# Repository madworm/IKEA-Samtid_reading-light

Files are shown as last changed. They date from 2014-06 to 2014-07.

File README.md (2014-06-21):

IKEA-Samtid_reading-light
=========================

LAYOUT FILES: Circuit board to go between the movable beams of the Samtid lamp.

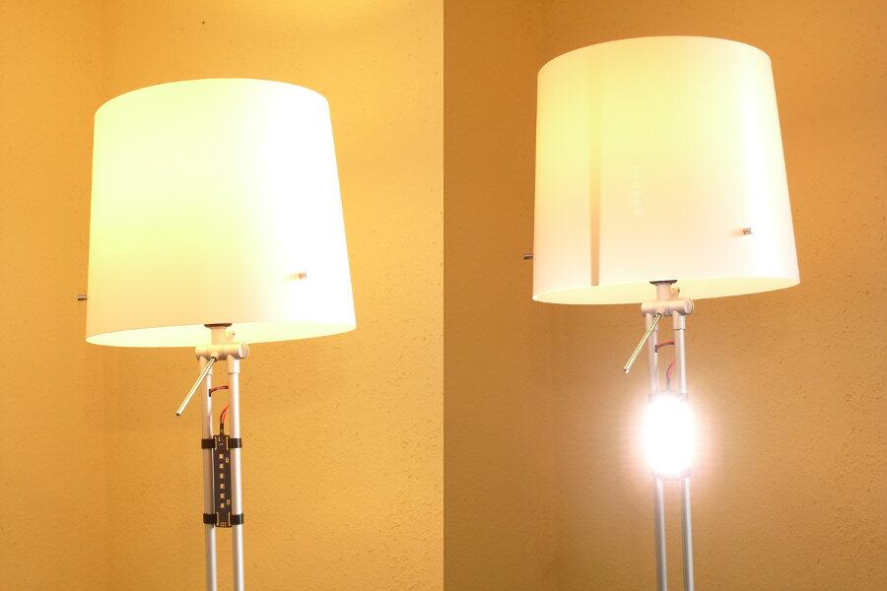
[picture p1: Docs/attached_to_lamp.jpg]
IKEA Samtid


---

Before having PC-boards made, please make sure you know about your manufacturer's peculiarities!
Especially drill-sizes and their tolerances may vary too much and give you trouble.

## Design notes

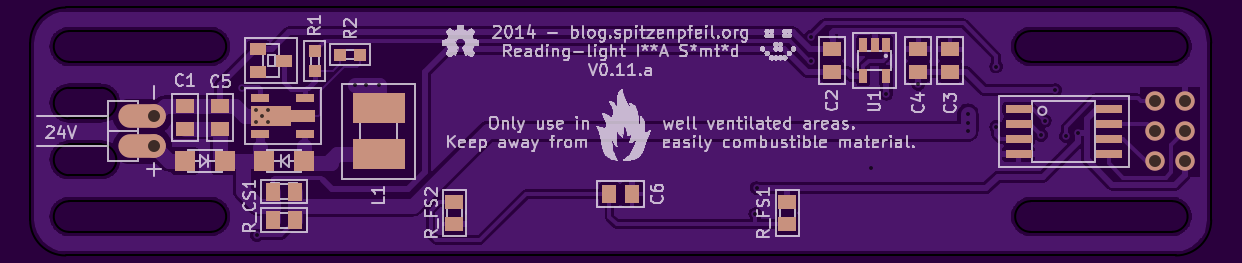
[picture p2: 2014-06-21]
gerber_files/PNGs/IKEA-Samtid_reading-light__back_purple.png

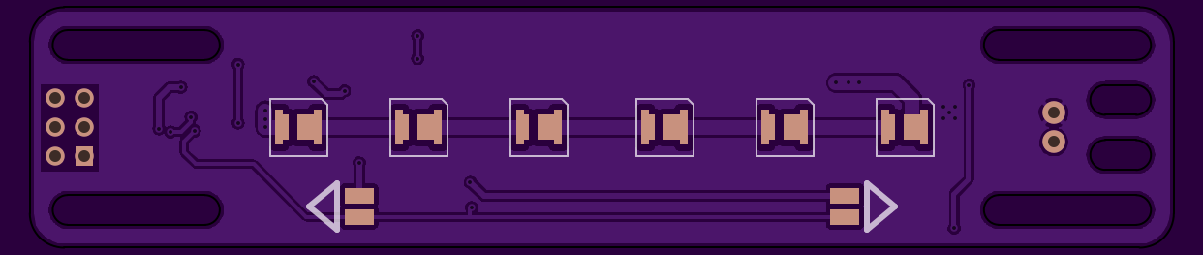
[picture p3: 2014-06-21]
gerber_files/PNGs/IKEA-Samtid_reading-light__front_purple.png

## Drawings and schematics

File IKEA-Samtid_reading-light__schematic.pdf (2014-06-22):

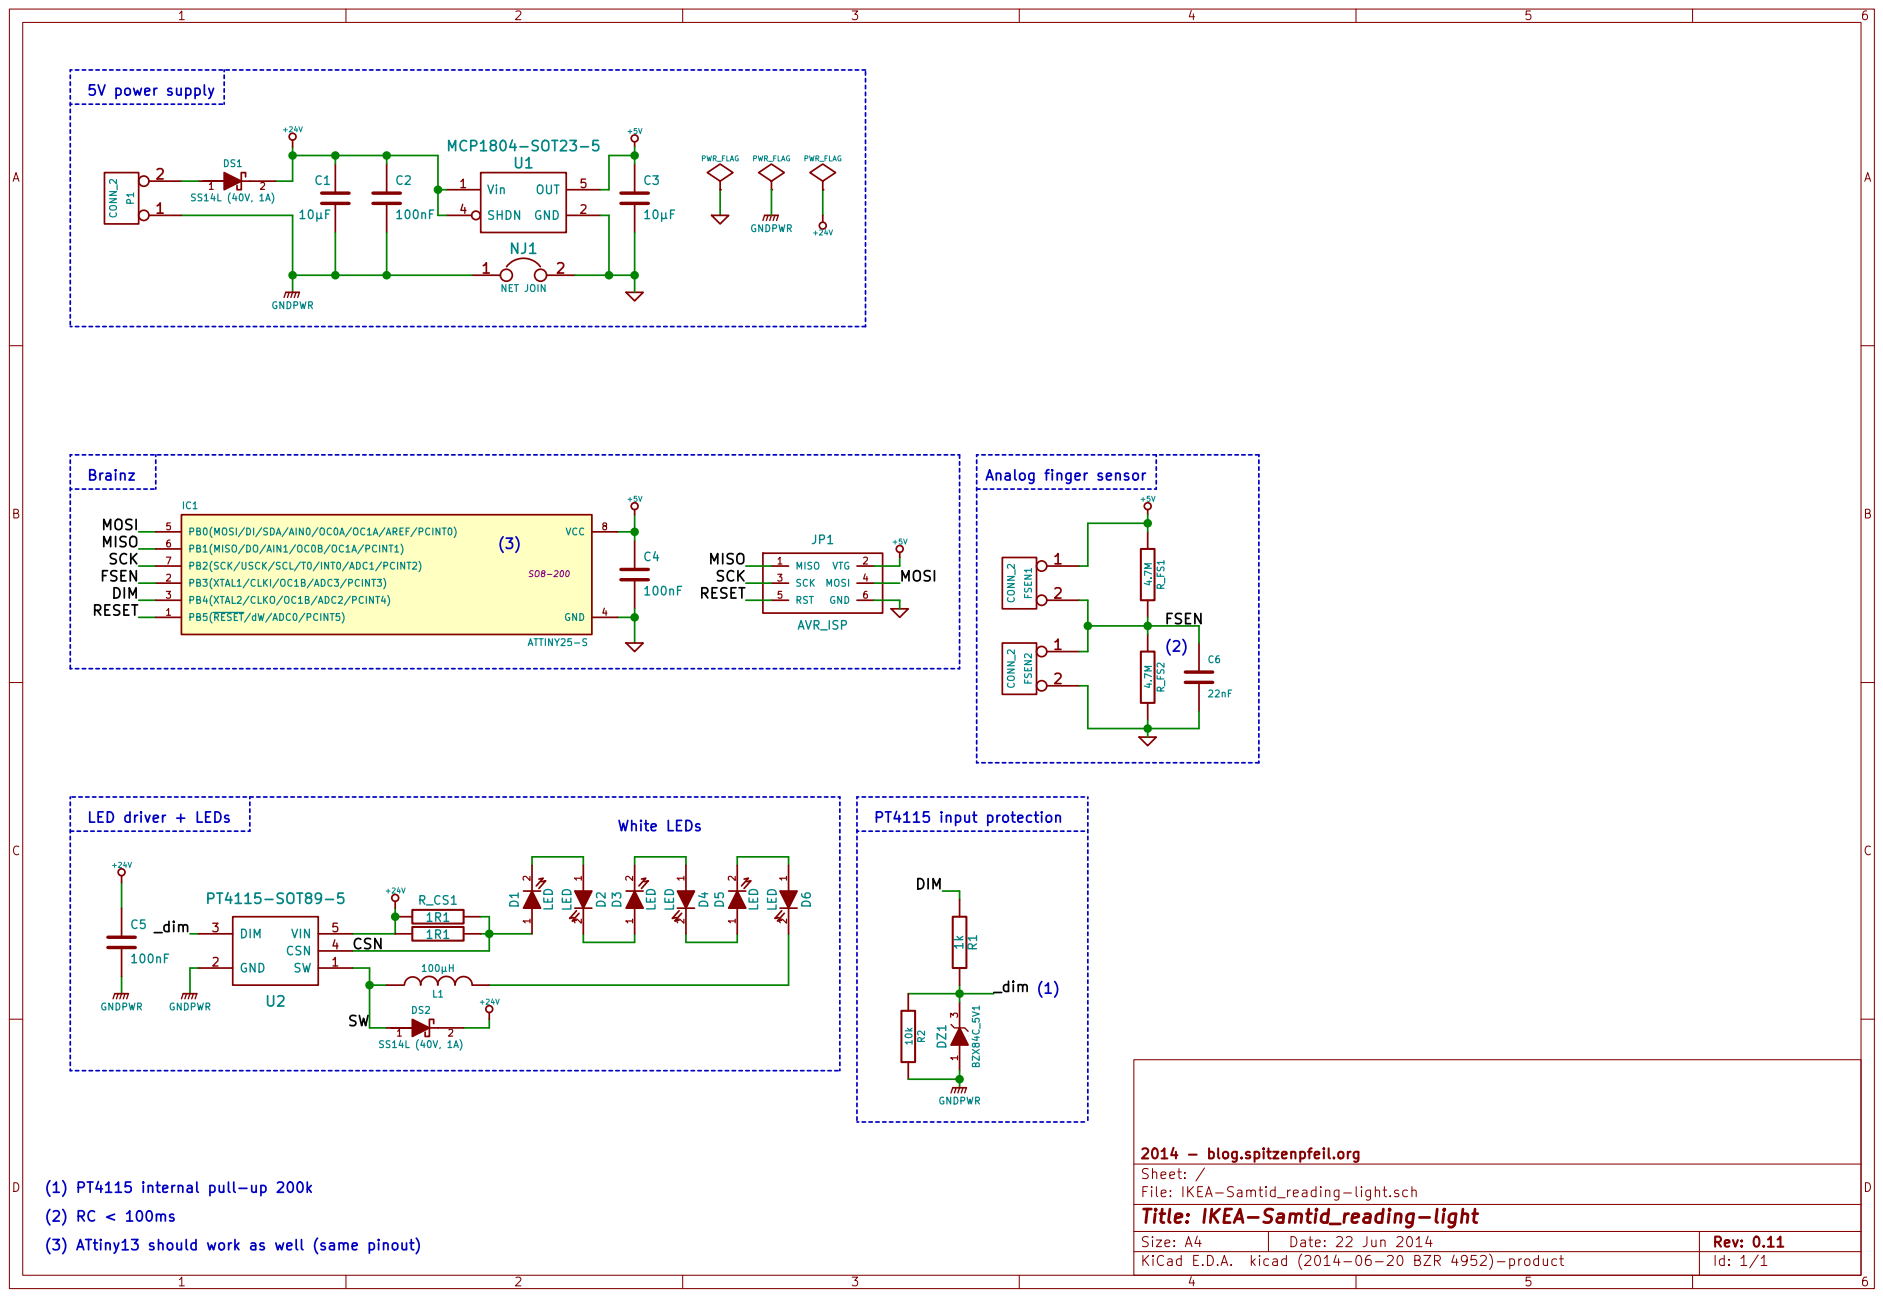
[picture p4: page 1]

PT4115 input protection Brainz LED driver + LEDs

File: IKEA-Samtid_reading-light.sch Sheet: / 2014 - blog.spitzenpfeil.org

(1) PT4115 internal pull-up 200k
(3) ATtiny13 should work as well (same pinout)

Id: 1/1 Title: IKEA-Samtid_reading-light

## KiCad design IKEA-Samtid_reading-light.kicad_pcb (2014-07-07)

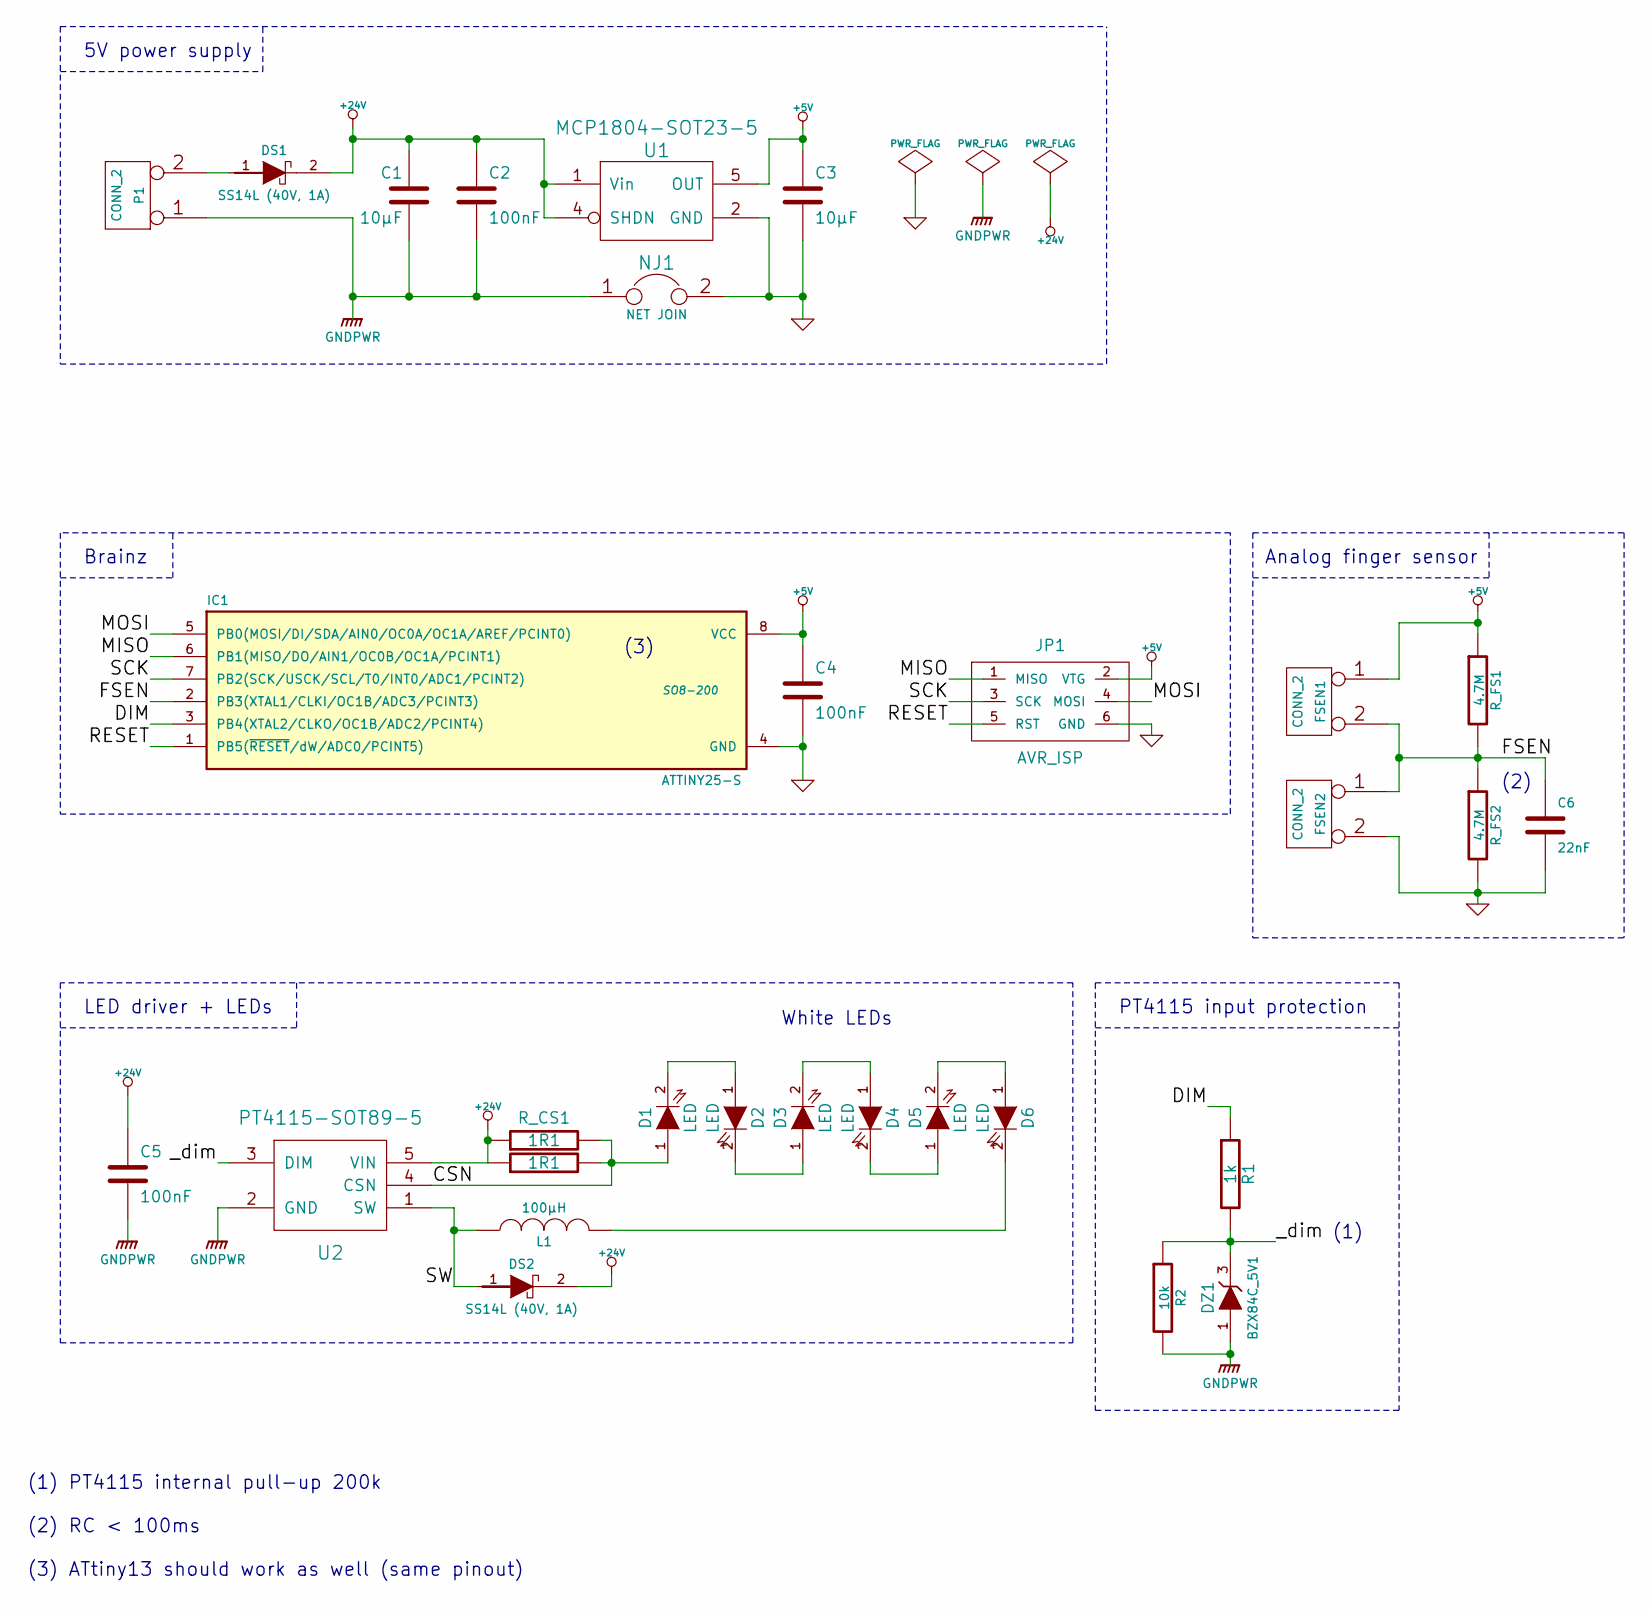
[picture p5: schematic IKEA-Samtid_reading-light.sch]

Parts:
C1, C3: 10µF
C2, C4, C5: 100nF
C6: 22nF
D1, D2, D3, D4, D5, D6: LED
DS1, DS2: SS14L (40V, 1A)
DZ1: BZX84C_5V1
FSEN1, FSEN2: CONN_2
IC1: ATTINY25-S; SO8-200
JP1: AVR_ISP
L1: 100µH
NJ1: NET JOIN
P1: CONN_2
R1: 1k
R2: 10k
R_CS1, R_CS2: 1R1
R_FS1, R_FS2: 4.7M
U1: MCP1804-SOT23-5
U2: PT4115-SOT89-5

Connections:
+5V: C3.1, C4.1, FSEN1.1, IC1.8 (VCC), JP1.2 (VTG), R_FS1.1, U1.5 (OUT)
+24V: C1.1, C2.1, C5.1, DS1.2 (C), DS2.2 (C), R_CS1.1, R_CS2.1, U1.1 (Vin), U1.4 (SHDN), U2.5 (VIN)
/CSN: D1.1 (A), R_CS1.2, R_CS2.2, U2.4 (CSN)
/DIM: IC1.3 (PB4(XTAL2/CLKO/OC1B/ADC2/PCINT4)), R1.1
/FSEN: C6.1, FSEN1.2 (PM), FSEN2.1, IC1.2 (PB3(XTAL1/CLKI/OC1B/ADC3/PCINT3)), R_FS1.2, R_FS2.1
/MISO: IC1.6 (PB1(MISO/DO/AIN1/OC0B/OC1A/PCINT1)), JP1.1 (MISO)
/MOSI: IC1.5 (PB0(MOSI/DI/SDA/AIN0/OC0A/OC1A/AREF/PCI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), JP1.4 (MOSI)
/RESET: IC1.1 (PB5(~RESET~/dW/ADC0/PCINT5)), JP1.5 (RST)
/SCK: IC1.7 (PB2(SCK/USCK/SCL/T0/INT0/ADC1/PCINT2)), JP1.3 (SCK)
/SW: DS2.1 (A), L1.1, U2.1 (SW)
/_dim: DZ1.3, R1.2, R2.1, U2.3 (DIM)
GND: C3.2, C4.2, C6.2, FSEN2.2 (PM), IC1.4 (GND), JP1.6 (GND), NJ1.2, R_FS2.2, U1.2 (GND)
GNDPWR: C1.2, C2.2, C5.2, DZ1.1, NJ1.1, P1.1, R2.2, U2.2 (GND)
unnamed: D1.2 (K), D2.1 (A)
unnamed: D2.2 (K), D3.1 (A)
unnamed: D3.2 (K), D4.1 (A)
unnamed: D4.2 (K), D5.1 (A)
unnamed: D5.2 (K), D6.1 (A)
unnamed: D6.2 (K), L1.2
unnamed: DS1.1 (A), P1.2 (PM)

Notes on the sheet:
White LEDs
Analog finger sensor
5V power supply
PT4115 input protection
Brainz
LED driver + LEDs
(1) PT4115 internal pull-up 200k (2) RC < 100ms (3) ATtiny13 should work as well (same pinout)
(1)
(2)
(3)

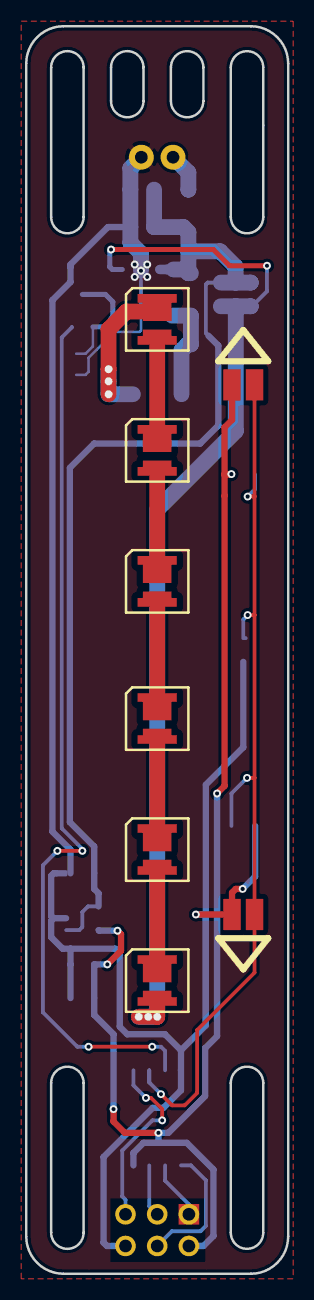
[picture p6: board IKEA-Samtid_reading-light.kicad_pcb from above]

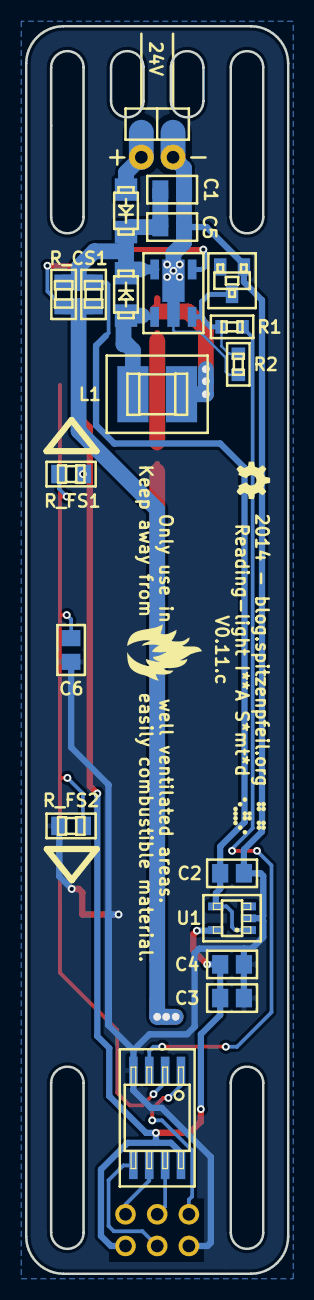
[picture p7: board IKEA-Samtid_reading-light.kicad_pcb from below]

Board: 2 copper layers, 21.0 x 100.0 mm, 33 parts (24 on the bottom side), 20 nets.

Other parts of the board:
LOGO1: LED_smile_silkscreen_3mm
LOGO2: OSHW-logo_silkscreen_3mm
LOGO3: fire_silkscreen-back_6mm

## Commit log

2014-05-27 Chose ATtiny25 for high-speed PWM (PLL).
    [IKEA-Samtid_reading-light.kicad_pcb, IKEA-Samtid_reading-light.sch]
2014-05-27 Shoving parts around.
    [IKEA-Samtid_reading-light.kicad_pcb, IKEA-Samtid_reading-light.sch]
2014-05-28 1st fully routed board (quite chaotic).
    [IKEA-Samtid_reading-light-B_Cu.gbl, IKEA-Samtid_reading-light-B_Mask.gbs, IKEA-Samtid_reading-light-B_Paste.gbp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]
2014-05-28 Moved layer-alignment mark to Eco1.User layer.
    [IKEA-Samtid_reading-light-B_Cu.gbl, IKEA-Samtid_reading-light-B_Mask.gbs, IKEA-Samtid_reading-light-B_Paste.gbp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]
2014-05-28 Routing + copper pour.
    [IKEA-Samtid_reading-light-B_Cu.gbl, IKEA-Samtid_reading-light-B_Mask.gbs, IKEA-Samtid_reading-light-B_Paste.gbp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]
2014-05-28 Back to 100mil AVR_ISP header + layout tweaks.
    [IKEA-Samtid_reading-light-B_Cu.gbl, IKEA-Samtid_reading-light-B_Mask.gbs, IKEA-Samtid_reading-light-B_Paste.gbp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]
2014-05-28 7mm --> 12mm slots (for 10mm tape) + shoved stuff around a bit.
    [IKEA-Samtid_reading-light-B_Cu.gbl, IKEA-Samtid_reading-light-B_Mask.gbs, IKEA-Samtid_reading-light-B_Paste.gbp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]
2014-05-28 Added slots for zip-ties.
    [IKEA-Samtid_reading-light-B_Cu.gbl, IKEA-Samtid_reading-light-B_Mask.gbs, IKEA-Samtid_reading-light-B_Paste.gbp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]
2014-05-28 Shoved parts around a bit. Visually more pleasing now.
    [IKEA-Samtid_reading-light-B_Cu.gbl, IKEA-Samtid_reading-light-B_Mask.gbs, IKEA-Samtid_reading-light-B_Paste.gbp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]
2014-05-28 R_FSx 1M --> 10M.
    [IKEA-Samtid_reading-light-B_Cu.gbl, IKEA-Samtid_reading-light-B_Mask.gbs, IKEA-Samtid_reading-light-B_Paste.gbp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]
2014-05-29 Striving for more horizontal symmetry.
    [IKEA-Samtid_reading-light-B_Cu.gbl, IKEA-Samtid_reading-light-B_Mask.gbs, IKEA-Samtid_reading-light-B_Paste.gbp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]
2014-05-29 Added a buffer-cap for the ADC input + minor layout tweaks.
    [IKEA-Samtid_reading-light-B_Cu.gbl, IKEA-Samtid_reading-light-B_Mask.gbs, IKEA-Samtid_reading-light-B_Paste.gbp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]
2014-05-30 Moved sensor pads away from LEDs + improved power input footprint.
    [IKEA-Samtid_reading-light-B_Cu.gbl, IKEA-Samtid_reading-light-B_Mask.gbs, IKEA-Samtid_reading-light-B_Paste.gbp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]
2014-05-30 ISP footprint tweaks. Mark pin #1 by square pad just on top layer.
    [IKEA-Samtid_reading-light-B_Cu.gbl, IKEA-Samtid_reading-light-B_Mask.gbs, IKEA-Samtid_reading-light-B_Paste.gbp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]
2014-06-20 Fixed wrong 5V regulator footprint. SOT23-5 was needed, used SOT23-6 :-(
    Quick fix for prev. boards: solder-bridge from pin #6 to pin #5 (SOT23-6 footprint).
    [IKEA-Samtid_reading-light-B_Cu.gbl, IKEA-Samtid_reading-light-B_Mask.gbs, IKEA-Samtid_reading-light-B_Paste.gbp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]
2014-06-21 Added a safety warning to silkscreen. This board gets quite hot.
    [IKEA-Samtid_reading-light-B_Cu.gbl, IKEA-Samtid_reading-light-B_Mask.gbs, IKEA-Samtid_reading-light-B_Paste.gbp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]
2014-06-21 Tweaks.
    1) C6: 100nF --> 22nF (faster response to finger touch). RC < 100ms.
    2) Added 10k pull-down for _dim on PT4115 to prevent / reduce LED flash on power-up.
    [IKEA-Samtid_reading-light-B_Cu.gbl, IKEA-Samtid_reading-light-B_Mask.gbs, IKEA-Samtid_reading-light-B_Paste.gbp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]
2014-06-22 Added comment to schematic (ATtiny13 vs. ATtiny25/45/85).
    [IKEA-Samtid_reading-light.sch]
2014-06-25 Silkscreen tweaks.
    [IKEA-Samtid_reading-light-B_Cu.gbl, IKEA-Samtid_reading-light-B_Mask.gbs, IKEA-Samtid_reading-light-B_Paste.gbp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]
2014-06-30 Some visibility settings were odd. Fixed that.
    [IKEA-Samtid_reading-light.kicad_pcb]
2014-07-07 Swapped R_FS1 & R_FS2 on PCB for same up/down operation front/back.
    [IKEA-Samtid_reading-light-B_Cu.gbl, IKEA-Samtid_reading-light-B_Mask.gbs, IKEA-Samtid_reading-light-B_Paste.gbp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]
